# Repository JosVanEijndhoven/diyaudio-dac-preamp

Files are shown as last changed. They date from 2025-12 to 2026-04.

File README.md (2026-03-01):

# DACXO: Audio DAC and digital pre-amp with low jitter

overview photo

## Introduction

This [github repository](https://github.com/JosVanEijndhoven/diyaudio-dac-preamp) 
provides all HW and SW sources of my DIY audio DAC design.
The audio 'Digital-to-Analog Conversion' is the heart and main aim of the design.
However, more audio device functionality was built around that:

- Functionality for a digital pre-amp is provided, with input selection
  and volume control. Inputs are optical and coax s/pdif, HDMI-arc, and a network DLNA audio player.
- The control UI (user interface) is created with [esphome](https://esphome.io/).
  Besides the front panel control knob, this also provides remote control from a mobile phone
  and/or integration in [home assistant](https://www.home-assistant.io/) automation environments.
- The core DAC design aims for high-end audio, with a focus on low jitter, not
  aiming to reach low component cost.

The intention of this repository is to show some solutions across a wide range of design choices,
potentially of interest to other DIY audio enthousiasts.
Supporting purely cloning the full hw/sw design is not the intention,
as some design files might be outdated for the various tools and components that were used:
the design start was around 2015. (But its development still continous in 2026...)
This DAC design builds on previous experience: it is already my 5th design.

Only in december 2025 I started to upload my design in github, and thereby make it public visible.
I still have to spend further effort in documenting the design and its choices.

The device name **DACXO** is related to:
- Its good **X**tal **O**scillator and low-jitter clocking.
- Its **X**tra **O**riginal clock synchronization scheme on the s/pdif inputs.
- The now **X** [years](https://en.wikipedia.org/wiki/Roman_numerals) **O**ld circuit design when creating this open-source repository.
- As bonus, the domain name [dacxo](http://www.dacxo.com) was available.

## Contents

This repository contains all hardware and software design aspects:

- The [front control and remote UI software](./esphome-ui/) based on a commercial *esp32-s3* board with display.
- The [digital signal processing board](./dacxo-hw/PCBs/PCB-dacxo/), schematics and PCB design.
- The [logic configuration of the FPGA](./dacxo-hw/FPGA-content/) on that board,
- The [analog output board](./dacxo-hw/PCBs/PCB-opampout/), schematics and PCB design,
- A [Linux kernel audio device driver](./dacxo-sw/RPi-audiodevice/),
  so that the board can also be driven from various applications on a Rapsberry Pi.
- Addition of a Raspberry Pi as [network media player](./dacxo-sw/), relying on above audio device driver.

## Focus on Jitter

The main focus on this design is having good behavior on jitter (that is, achieve very low jitter).
Already for decades now, jitter is known to badly affect the sound quality of digital audio reproduction.
Unfortunately, achieving low jitter makes a device more expensive, and measuring jitter behavior requires expensive specialised equipment.
As result, many digital audio consumer products still show bad jitter behavoir.

The audible effects of jitter in a digital audio player are:

- Weak, uncontrolled, bass
- Unfocussed and unstable stereo imaging
- Unpleasantly sharp (metal-sounding) highs

Because many (cheaper) audio consumer devices behave badly in this respect,
the old vinyl record playing has risen again in popularity.
Luckily, good digital audio players don't show these artifacts,
and can sound really natural and convincing!

Presumably in large part due to jitter effects, this DAC design sounds significantly better than for instance the
[Cambridge Audio EXN100 player](https://www.cambridgeaudio.com/row/en/products/ex/exn100) which I bought early 2025, 
which costs around 2000 US$. (Just in my opinion and some of my audio-loving friends.)

For further background information on jitter in digital audio, you can easily find many sources on internet.

As a final note, jitter artefacts do not only occur in audio DAC (digital-to-analog conversion),
but similarly in analog-to-digital conversion (ADC).
So, a poor-quality studio recording (or home recording)
will introduce jitter artefacts in the digital audio stream.
Once in there, these jitter artefacts cannot be removed anymore:
a bad recording will sound bad forever. 
A good low-jitter player cannot improve a bad recording.
Unfortunately, it seems to me that there are many bad-quality recordings around...

## License
All source and configuration files provided in this repository are provided without any warrenty,
and under copyright and license:

Copyright 2025 Jos van Eijndhoven

[GNU General Public License v3](https://www.gnu.org/licenses/gpl-3.0.nl.html)

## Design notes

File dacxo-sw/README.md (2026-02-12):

# Audio stream DLNA renderer to the DAC

## Introduction

To stream audio to the DAC over wifi, a 'DLNA' network
interface is created.
This is realised with a tiny
[Raspberry Pi zero 2W](https://www.raspberrypi.com/products/raspberry-pi-zero-2-w/).

For streaming audio,
(DLNA renderer)[https://github.com/hzeller/gmrender-resurrect] software is installed. This allows other application to send audio,
in particular [BubbleUpnp](https://play.google.com/store/apps/details?id=com.bubblesoft.android.bubbleupnp),
or maybe [VLC](https://github.com/videolan/vlc).

The received audio is passed to the DAC board through an *i2s* interface.
[i2s](https://en.wikipedia.org/wiki/I2S) in general allows a configuration choice whether the
sender or the receiver provides the clock signal.
Here the DAC provides its 'master' clock,
which means that there is no synchronization issue.
That is a major advantage over using s/pdiff interfaces.

## Installing the DLNA renderer

The (gmrender-resurrect)[https://github.com/hzeller/gmrender-resurrect]
software is installed on the *raspberry Pi zero 2w* according to
its description. That description is fine: although it mentions
*gstreamer1.0* in some of its package names, it actually
instals the recent versions of that.

Created *gmedia* user to run the daemon:
```
sudo adduser --system --ingroup render --no-create-home gmedia
sudo usermod -a -G audio gmedia
sudo usermod -a -G i2c gmedia
sudo usermod -a -G gpio gmedia
```

Edit the `scripts/init.d/gmediarender` file, modifying a few lines such as:
```
DAEMON_USER="gmedia:audio"
UPNP_DEVICE_NAME="MyDac"
ALSA_DEVICE="plughw:DACXO"
start-stop-daemon -x $BINARY_PATH ... --mime-filter audio
```
(On the long `start-stop-daemon` line, add the `--mime-filter audio` option
restricting this *dlna renderer* to only play audio, not video.)

Then, install it with:
```
sudo cp scripts/init.d/gmediarenderer /etc/init.d
sudo update-rc.d gmediarenderer defaults
```

## System load for playing audio streams over wifi

My small *Rapsberry Pi zero 2W* seems just fine and powerful enough
for this task. For example, a *high resolution* FLAC-encoded stream can easily be
sent to this *DLNA renderer*.
A *96K* samplerate and *24-bits* per sample stereo FLAC stream has
a variable bandwidth of roughly 400KBytes/sec. For such a stream,
the renderer uses about 7% cpu load (on 1 of the 4 available cores)
and takes about 25% (or 125MB) of the available 512MB memory.

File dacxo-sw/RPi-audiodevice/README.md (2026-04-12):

# Audio device driver for Linux

## Introduction

This DAC design initially/traditionally focussed on using the four s/pdif inputs on its digital board: two coax and two optical inputs.
However, the board also provides a fifth digital audio input:
an [i2s](https://en.wikipedia.org/wiki/I2S) input intended to connect
an audio network streaming device in the form of a Raspberry Pi.
I chose a tiny
[Raspberry Pi zero 2w](https://www.raspberrypi.com/products/raspberry-pi-zero-2-w/) for this purpose.

Connecting a Raspberry Pi through its *i2s* interface (in this design) keeps the DAC as
master clock, and uses the Pi as clock slave on this interface:
- This has the advantage of a clean clock with minimal jitter without any clock synchronization issues.
  (In contrast with using the classic s/pdif inputs.)
- It requires that -per song- the Pi informs the DAC board on the required sample-rate.

So, where the *i2s* interface is used to pass the audio data,
the Pi also uses an [i2c](https://en.wikipedia.org/wiki/I2C) connection
to the DAC board to communicate on the sample-rate.
In practice, this also enables the Pi to control the audio volume, input selection, and power-state,
and make the Pi a full-featured audio streamer.

For the Pi to obtain such control, it needs an audio device driver.
Such Linux kernel audio device driver is provided in this directory.

## Contents
- Creating the development setup
- Building and installing the device driver
- Initial testing of the device driver
- Activating the device driver on boot
- Choosing the DAC as system default audio device

## Creating the development setup
To build the device driver kernel modules, I opted (and would recommend)
for the simplicity of doing that on the target Raspberry Pi itself.
This as opposed to a more elaborate setup of a Pi cross-development environment
on another desktop computer.
Building and installing the kernel modules is highly dependent on the
precise version of the Linux kernel. Local development avoids a potential mismatch.
Also, after an OS update which increments the kernel version, these modules
can be easily rebuilt. 

The start environment is the plain [64-bit Rasberry Pi OS](https://www.raspberrypi.com/software/operating-systems/).
The *Lite* version, without desktop environment, is fine: we will only use
the Linux command-line [through an 'ssh' connection](https://www.raspberrypi.com/documentation/computers/remote-access.html#ssh).
Optionally, it might also be convenient to [share your Pi home directory](https://www.raspberrypi.com/documentation/computers/remote-access.html#samba) with your desktop.

All further text in thie README assumes that you are logged-in on the Pi,
maybe through *ssh*, and execute the commands locally on the Pi.

The Raspberry Pi OS comes with `gcc` and the required `include` files pre-installed, so we don't need to install that.

To obtain a copy of the source code in the Pi, it is easiest to install
`git`:
```
sudo apt install git
```
Since this git repository contains many more things, for just building
the Pi device drivers you probably want to `checkout` only the relevant directory.
That gains speed and reduces the size on your Pi's memory card.
```
git clone --filter=blob:none --sparse  --depth 1 git@github.com:JosVanEijndhoven/diyaudio-dac-preamp.git
cd diyaudio-dac-preamp
git sparse-checkout set dacxo-sw/RPi-audiodevice
git checkout
```
Now, `cd dacxo-sw/RPi-audiodevice` to see what you got and start building.

## The device driver source code files

The device driver C-code sources consists of various files in the `bcm` and `codecs`
sub-directory.

1. `bcm/dacxo_bcm.c`: This is 'board control module', it specifies that there is an *i2c* connection to the board, to control the FPGA and the two pcm1792 dac chips.
Around [dacxo_bcm.c:343](dacxo_soc_modules/bcm/dacxo_bcm.c#L343)
the *i2s* interface mode is set to `DACXO_DAIFMT`.
This is defined in `codecs/dacxo.h` with (among others)
the value of `SND_SOC_DAIFMT_CBP_CFP`. This configures the Pi *i2s* interface
as clock slave, for both the bit-clock and the word-clock.
This board driver also takes care of powering-up the board if it would be in *standby*.

2. `codecs/dacxo_codec.c`: It implements the *per audio stream*
dac sample rate control with the i2c registers in the FPGA.
3. `codecs/dacxo.h`: constants regarding the codec, also passed to the `dacxo_bcm.c`.
4. `codecs/pcm1792a.h`: constants to drive the pcm1792a on-chip registers. code.

## Building and installing the device driver

The `Makefile` in this `RPi-audiodevice` directory defines targets for many actions.

The `dacxo` device driver consists of two kernel modules:
- `dacxo_bcm`, the *board control module*, or *card driver*.
- `dacxo_codec`: the *codec* module.

To just build these in the current directory tree, you do:
```
make modules
```
The two built modules can be seen with `ls -l */*.ko`.

Besides these kernel modules, the driver needs a *device tree overlay*.
This specifies how/where these modules need to hooked into the Linux device tree.
This *device tree overlay* also needs to be compiled. So run:
```
make overlays/dacxo.dtbo
```

If there are no fatal errors, proceed with installing these build results
in the Pi system directories. The following command uses `sudo` and might
ask for your password:
```
make install
```
It would be good to have the `i2c` and `i2s` connections activated in
the `/boot/firmware/config.txt`, by adding (uncommenting) the
following two lines. If they were absent, do a reboot:
```
dtparam=i2c_arm=on
dtparam=i2s=on
```

Now one can load the `dacxo` driver at runtime in the kernel:
```
make test_dtoverlay
```
The above command will show some log output (from `dmesg`), from
loading and initializing the driver.

When encountering issues, the installation and overlay can be undone with:
```
make uninstall
```
Also, local build artefacts can be removed with:
```
make clean
```

Until now this is all reasonably safe: a next reboot will not yet
automatically load the driver, so there is no risk of destroying a clean boot.

The driver code and its overlay were developed on the 64-bit Pi OS of December 2025,
debian version 13 (trixie), with Linux kernel *6.12.62+rpt-rpi-v8*.
Recent history has shown that the Linux audio (ALSA) kernel api's do not remaain very stable over time.

## Initial testing of the device driver
If making the `test_dtoverlay` seemed OK, without errors, audio can be played!
For instance by:
```
make sound
```
The card properties that the driver exposes to ALSA can be seen with:
```
make show_card
```
The low-level device registers on the *i2c* bus (in the three different
i2c devices of this card) can be examined at runtime
through the Linux *debugfs* mechanism with:
```
make show_registers
```
Note that on receiving fisrt audio, this device driver will automatically
power-up the DAC if it was in standby, and select its *i2s* input.

## Activating the device driver on boot
After some testing, the installed driver can be made to
automatically active on every boot.
There are two mechanisms to achieve this. Choose one of:
1. Add a line in `/boot/firmware/config.txt`:
```
dtoverlay=dacxo,sync_pin=27
```
2. Use the Linux *systemctl* service mechanism for this:
```
make install_service
```
The latter option allows to *start* and *stop* this at runtime,
which had my preference.

## Choosing the DAC as system default audio device
Note that the above `make install` will also install the `etc/asound.conf`
as provided by this repo. That makes the new *dacxo* device as the default
audio device. On my *Pi zero 2w*, the default audio device is otherwise
its hdmi output. Of course, alternatively, one can probably also configure
the `dacxo` audio output specifically for the audio media player application.

This device driver announces to the Linux ALSA system that it accepts audio
streams with samplerates: `44100`, `48000`, `88200`, `96000`, `176400`, and `192000`.
It accepts audio formats with `16` or `24` bits per sample, and 2 channels (stereo).

In the proposed `asound.conf`, the default audio is created with `type plug`,
which means that the kernel can *plug* format conversions if deemed necessary
to play some audio stream. This is needed in particular for playing
24-bit FLAC streams: after basic decoding (such as by the `flac` application),
a *compact* 3-bytes-per-sample stream is created.
The Pi cannot send such stream to its *i2s* output with DMA.
The `type plug` will automatically insert a software filter that performs
*zero-padding* to extend each sample to 32-bit.
Such *plugging* would also be done for instance for mono audio streams.

## Raspberry Pi I/O pins used by this driver

The below diagram shows the pinout of the three *i2s* signals and two *i2c* signals on the Pi
40-pin GPIO connector:

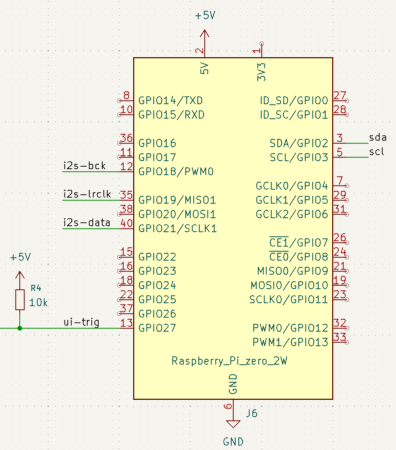
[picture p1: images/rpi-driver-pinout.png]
RPi schematic diagram of I/O


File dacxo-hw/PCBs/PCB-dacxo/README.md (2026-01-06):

# Audio DAC main digital PCB
## Introduction
The 'digital PCB' implements the most interesting parts of this DAC design.
It is provided here with a global description below, pdf files
of the [schematics](./dac5-schem-eurocircuits-20150214.pdf) and
[PCB layout](./dac5-eurocircuits.pdf), and the original [KiCad](https://www.kicad.org/) design files.

## Board inputs and outputs

The PCB provides five digital audio inputs:
  - Two optical s/pdif inputs
  - Two coax s/pdif inputs
  - One i2s input

The analog audio outputs are *intermediate*, needing further handling by a separate analog PCB.
These outputs are the direct chip outputs of the (now mounted) pair of *PCM1792A* DAC chips.
They operate in *dual mono* mode, and provide for each audio channel a differential current output of 2x 15.6mA p-p, on top of a DC current offset of 12.4 mA.

For control of the board, an i2c input is used.
An external microcontroller board shall be used to implement the control. This includes settings such as:

- Setup initialization of chip operating modes.
- Audio volume and balance
- Input source selection
- Power on versus standby mode

Besides these settings, the microcontroller can read status information such as:

- currently selected xtal oscillator
- signal presence and sample rate of the current s/pdif input
- current status of the audio buffer and clock rate adjustment (see PLL description below)

Based on the s/pdif received audio signal, the board hardware will automatically select
one the two xtal oscillators and a clock divider to match the samplerate of the signal.
This logic is implemented in the on-board FPGA, a *MachxXO2-100* from Lattice Semiconductor,
denoted *U306* in the [schematics](./dac5-schem-eurocircuits-20150214.pdf).

For power supply, the board takes a separated:

- Analog supply as a raw (unrectified) input from 2x7V transformer.
- Digital supply as a raw 5V dc from an external small smps (switch-mode power supply).
  The chosen 1A (5 watt) power is plenty for this design.
  I selected a high quality type, approved for medical applications, manufactured by Mean Well.

Furthermore, the board provides:

- a USB input for programming the FPGA.
- several connectors for easy access to measure and debug various on-board signals.
- a few LEDs for quick visual feedback on status.

## s/pdif receiver

The CS8416 (*U503* in the [schematics](./dac5-schem-eurocircuits-20150214.pdf))
is used to receive the s/pdif datastream and select between
four inputs: two optical and 2 coax. The coax inputs are implemented with high-frequncy isolation transformers
for a good isolation of common-mode disturbance. In general, coax connections seems to have a preferrable
signal transfer.

The PCB allows the CS8416 to operate in eiter its 'SW mode' or its 'HW mode'.
A 47k resistor can shall placed in either *R505* for SW mode, or in *R501* for HW mode.
Initially, during board testing, SW mode was used. In the final design, HW mode is used,
where the various control wires are provided by the FPGA.
(The two modes rely on a different FPGA content.)

The audio clock which is recovered by the CS8416 from s/pdif is in sync with the audio bitstream,
and used to clock the audio data into the FPGA buffer. This clock is considered *dirty* in this design,
so is NOT used for the output clock on the DAC chips.

## Achieving low jitter

To achieve low jitter performance, different causes of jitter need to recognized and addressed.
This is distinguished in aspects 1 to 5 below:

### 1. Oscillator (reference clock) stability
Low jitter in the main audio reference clock, corresponds to low oscillator phase noise.
This design uses the Crystek CCHD-957 crystal oscillator, which has the best phase noise specification I could find,
while easy to acquire in small volume. Phase noie is typically expressed in a frequency plot. A key number
would be the *-130dB noise level* at *100Hz deviation* from its center frequency.
The design actually uses two of these oscillators, at 45.1584 MHz and 49.152 MHz.
These frequencies correspond to 1024 * 44.1 kHz and 1024 * 48 kHz. Having both these clock frequencies
allows the playback of relevant audio sample rates without complex (non-power-of-two) resampling,
to avoid related conversion artefacts.

### 2. Re-clocking of digital audio signals
To achieve low jitter on the signals that enter the DAC chips, the audio data, audio bit-clock and audio word-clock signals
are *re-clocked*: they pass through a clocked register (U307 in the schematic) which is
clocked directly by the xtal reference clock. There should be absolutely minimal (best none at all) logic between
the crystal reference clock and the clock input of this register.
This shall minimise the build-up of jitter on signals that pass through logic gates.

### 3. Low-noise power supply on the digital ciruits
All CMOS logic gates have a gate-delay which strongly depends on the power-supply voltage.
You can easily check this on any *74hc* logic family datasheet. A gate delay of -lets say- 10ns can easily vary +/- 1 ns
when its powersupply voltage has small dips or peaks. That is an *enormous* variation in delay, as we aim for
jitter in the 10ps to 100ps range. Note furthermore, that we need to have a stable power supply voltage
*on the chip die itself*, not only on the external package pins.
This results in a preference for less logic per chip, less logic sharing a common power-supply pin.

In this schematic, the *3.3Vana* is made from a 2.5V reference, RC-filtered for noise,
and amplified/buffered with a low-noise opa2227 opamp.
This low-noise supply voltage is used for the crystal oscillators, the re-clock register,
and the digital supply of the DAC chips.
In *standby* mode, this *3.3Vana* with its off-PCB transformer is switched off.

The other digital circuitry (the FPGA and the s/pdif receiver) are supplied from a separate 3.3V 'digital' power voltage.
This same 'digital' power supply also provides a +5V to the front panel microcontroller
through the 4-pin i2c connector (P402 in the schematics).
The 'digital' power comes from an off-board +5V small SMPS (switch-mode power supply).
In *stand by* mode, this 'digital' power will remain on.

### 4. Reduce EMI-induced noise
Electromagnetic Interference (EMI) induced noise is caused by high-frequency
elecromagnetic fields that spread around the PCB surface, and can cause
signal degradation and jitter. (Here, with 'high frequency' we worry about
frequencies in the order of 100Mhz to 1GHz.)

For a clean supply voltage and reduced EMI fields, a well-designed
[power-supply decoupling](https://www.murata.com/en-eu/products/emc/emifil/library/knowhow/basic/s2-chapter06-p1)
is required on all digital ICs.
This is achieved by:

- a local power supply decoupling capacitor very close to each chip.
- a high-frequency-suppression chip-inductor in the power-supply line for each chip.

The inductor makes sure that the high-freqency switching currents remain local to the chip and its decoupling capacitor.
Keeping these currrents local (in a very small loop) strongly reduces the EMI noise around the PCB.

Furthermore, small (47R to 470R) series-resistances are inserted in series in many
of the audio data and clock lines. These reduce peak currents
and [high-frequency ringing](https://www.protoexpress.com/blog/how-to-reduce-ringing-in-pcb-designs/)
on these signals on the PCB.

### 5. Phase Locked Loop design
Creating a good-sounding DAC from s/pdif inputs (optical or coax) poses a major extra challenge on *clock synchronisation*.
Note that an i2s or usb sound input can easily and totally avoid this issue.
S/pdif audio is received with its own clock. Recovering that received clock from the s/pdif signal
inevitably leads to a bad (unstable, high jitter) clock signal.
Unfortunately, a local fixed-frequency crystal oscillator cannot directly replace
that 'bad' clock, because it typically deviates from the frequency of the received
audio data stream: crystal oscillators typically deviate by +/- 100ppm (or 0.01%) from the nominal frequency (and the received stream).
To overcome this potential difference in center-frequency, some solution must be implemented.

*Option 1:*
Directly using the s/pdif retrieved clock for the DAC output is only done in the cheapest designs,
with crappy sound quality. The local crystal oscillator is simply omitted.

*Option 2:*
Traditionally, in vintage designs,
a clean clock might be re-created with an analog 'phased locked loop' (PLL). Such PLL contains a VCO (or VCXO): an oscillator
of which its frequence can be slightly tuned by an applied input voltage.
If the PLL has a low-frequency and low-noise filter for the control voltage, the jitter in the re-created clock
can be much lower then in the s/pdif-recovered clock.
In theory this can be good, but in practice this is extremely hard. Even good-quality VCXOs (voltage controlled crystal
oscillators) exhibit *much* higher jitter then the best fixed-frequency crystal oscillators.

*Option 3:*
Currently used by most DAC designs: The DAC always already contains a digital filter for purposes of sample rate
conversion (translating all digital sources to a common rate for the output) and oversampling (creating a
higher sample rate on the output). Now, if a 'dirty' input clock that provides the audio samples slightly deviates
in its average from the local fixed-frequency crystal oscillator, lets say by 100ppm, then after every 10.000 samples
some *new* sample must be inserted, or some received sample must be dropped. The digital filter
can then be used to 'smear' this sample artefact over a longer period.
As result, short-term (fast) jitter in the dirty input clock nicely disappears,
but very slow jitter in the input and deviation in the average data rate,
result in distortions (modified values) in the filtered output.

*Option 4:*
This DAC design takes a new approach, as far as I know. The input samples with their 'dirty' s/pdif clock are
stored in a cyclic buffer (a queue of samples). This buffer can be relatively small,
in this design it currently is 682 samples.
The high-quality crystal clock is used to take samples out of this queue to send to the DAC chips.
Note that this design uses an xtal clock of 1024x the standard (44.1kHz or 48kHz) sample rate.
If the buffer runs low (nearly empty), the clock divider to create the sample rate (word-)clock, is adjusted to be 1025.
Similarly, if the queue runs nearly full, the clock divider can be adjusted to 1023.
Effectively, this creates a nearly 0.1% deviation in the output clock rate.
Switching the output clock frequency +/- 0.1% occurs at low rate:
Suppose 640 samples in the queue need to be flushed or filled
at the modified frequency, that would take (640 / (samplerate x 0.1%)) is about 14 seconds.
Having the DAC speed-up or slow-down the output rate by 0.1% after about 14 seconds is truly in-audible.
For a high-resolution 24bit 96kHz datastream the duration of the updated clock speed is still about 6.6 seconds.
This design choice can be considered a digital PLL, with a very low-frequency filter loop.
Obviously, the good properties are that a) a high-quality low-jitter clock can be used,
and b) all original audio sample values are retained as is.

Because the number of buffered samples remains relatively small, it imposes a delay of at most 14 millisecond,
which means that the audio will remain in sync with video if the audio stream comes from an attached TV.

## i2s input

The extra i2s input is on the PCB as *P408*.
In i2s mode, the PCB assumes clock master mode, where it provides the bit-clock and word-clock to the interface.
So the peripheral (audio streamer) should:

1. Configure its i2s output in clock slave mode.
2. Pass control information from the audio stream through i2c to the FPGA to indicate
   the required sample rate.

In this clock master mode, there is no need to synchronize with any other clock.
Therefor, the fifo audio buffer is not used, nor is the +/- 0.1% clock rate adjustment.

On *P408*, the following pin assignment is used (set by the FPGA configuration):

- pin 1: gnd
- pin 2: audio data input
- pin 3: word clock output
- pin 4: bit clock output

After buffering with the crystal clock, these signals are passed as-is to the PCM1792 DAC chips.
So their format (e.g. msb-first, left aligned) should match.

## Selection of DAC chip
The PCB provides footprints for two different DAC chips: a pair of PCM1792A, or alternatively a pair of WM8741.
This is intended for comparison, but for now only the PCM has been used.
Clearly, only one of those pairs should be mounted!

## FPGA programming
The FPGA is a [Lattice Semiconductor MachXO2 family](https://www.latticesemi.com/en/Products/FPGAandCPLD/MachXO2)
device, in particular the LCMXO2-1200HC-4TG100I.
This FPGA features internal configuration storage, so no extrernal flash memory is needed.
It is housed in 100-pin TQFP package, which can still (barely) be hand-soldered on the PCB:

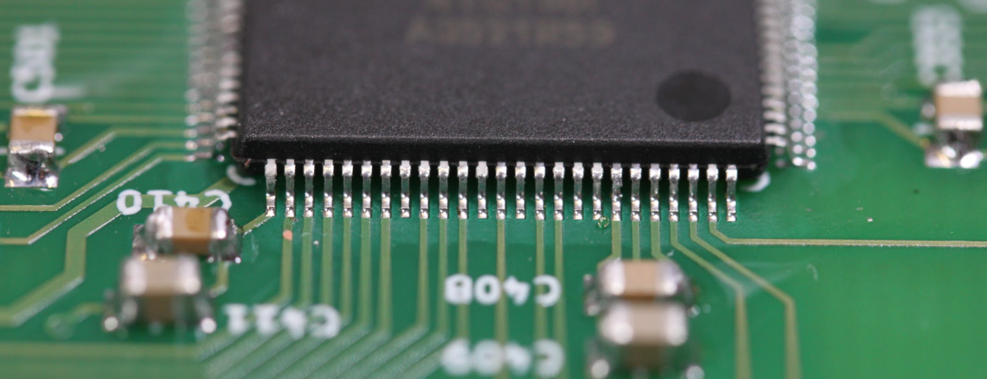
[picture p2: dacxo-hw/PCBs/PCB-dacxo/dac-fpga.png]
FPGA soldering


For easy programming of the onboard FPGA, a USB-to-jtag module is added to the PCB, denoted as *U401* in the schematics.
This is a DLP-USB1232H module from DLP Design. It is only used for programming the FPGA. During normal DAC
operation the module can harmlessly stay in place or can be removed.
During programming, the PCB takes +5V from this module, and no other external power is needed.
Note that there exist some late PCB wiring patches around its connection.

## On-board LEDs for diagnosis
The PCB has a number of LEDs that were convenient during early board
testing and debug. These are five bi-color (red-green) LEDs.
Their on/off status is according to the following table in matching top-down order:

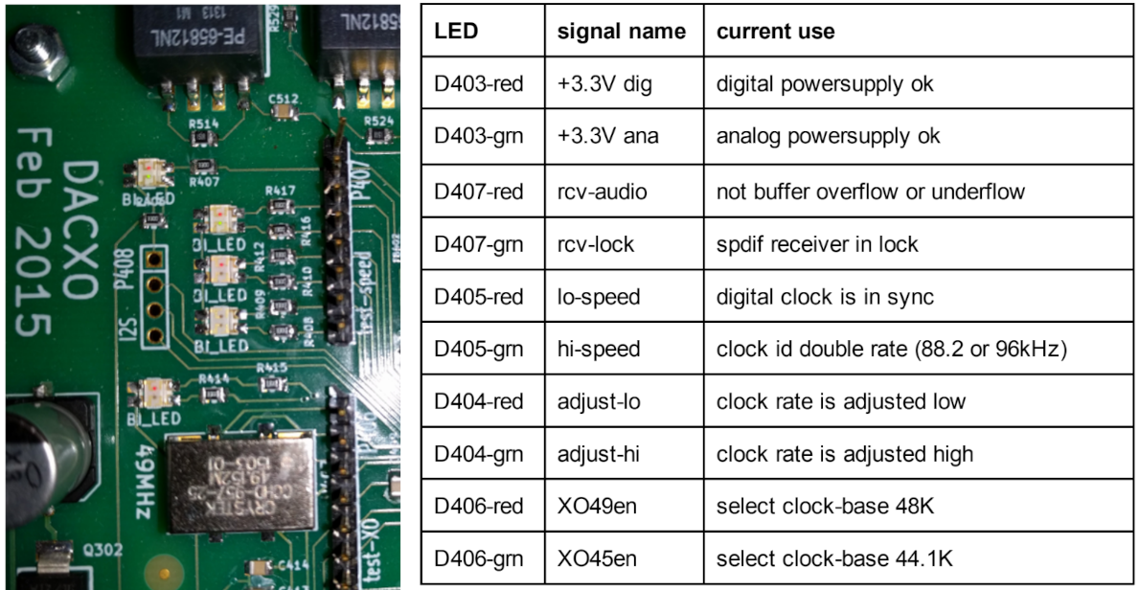
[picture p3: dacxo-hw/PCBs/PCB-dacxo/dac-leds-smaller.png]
LED status usage


## Late patches on the digital PCB
After assembly and test, a couple of small patches were done. These are not shown in the
original Kicad schematics: those still belong to the PCB design.

1. Add a small rectifier diode from '+5Vana' to 'V5raw' for protection against power-up errors.
2. 'U403' (for jtag programming) was badly connected: Lift 'pin1' to de-connect from the pcb,
  connect it to 'pin15' and 'pin8', and connect that triple to 'gnd'.
3. Replace R503 (47k) with 47 ohm.
4. Add a 4k7 resistor from 'rcv-rst' to 'gnd'.

Details on 2:
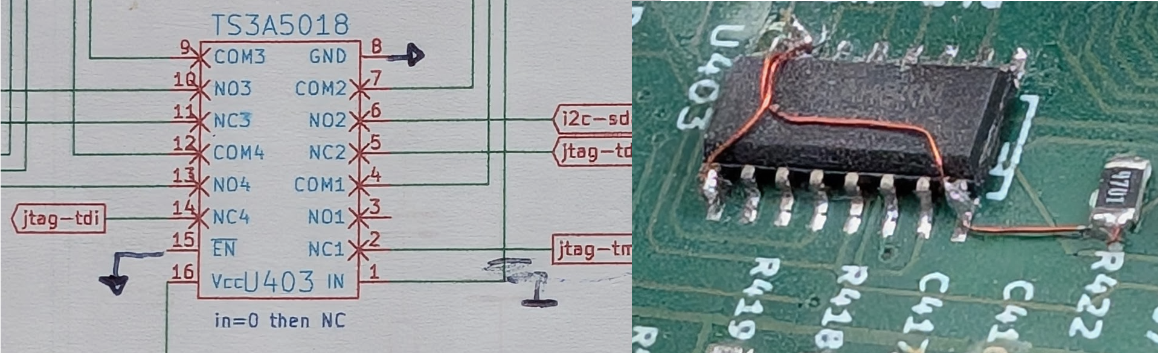
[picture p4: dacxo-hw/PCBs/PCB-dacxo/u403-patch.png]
patch on U403

Pin 1 got lifted from the PCB, which is hard to see in the photo.

Details on 4:
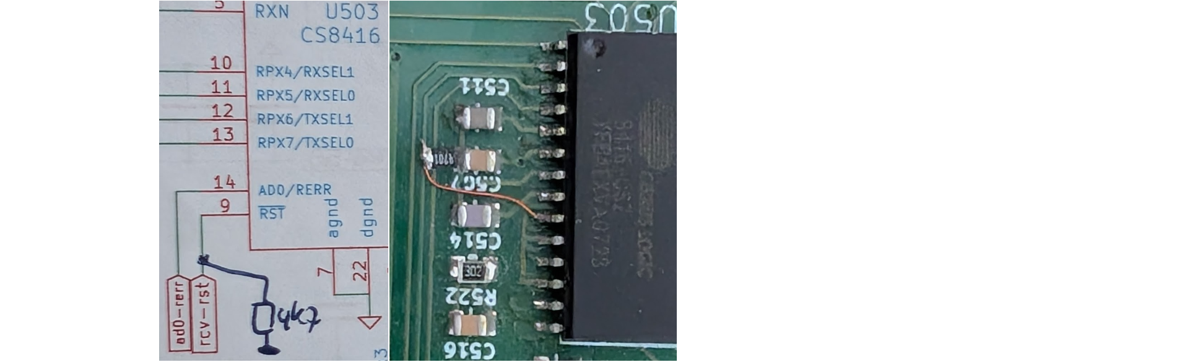
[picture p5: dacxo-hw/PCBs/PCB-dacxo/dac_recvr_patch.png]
patch on u503


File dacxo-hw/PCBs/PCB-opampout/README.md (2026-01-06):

# Analog output stage
## Introduction
This PCB provides a textbook style opamp-based analog output to accompany the digital PCB.
It was designed to function as basic reference (starting point) for other
more high-end analog audio alternatives.

The main functionality of this board is:

- Implement the current-to-voltage conversion that is needed for the (current output of) the PCM1792a DAC chips.
- Create stereo balanced output on a pair of XLR connectors,
  next to a conventional (single-ended) cinch connector.

The [schematics](./SchemaOutput-20131124.pdf) and the
[PCB layout](./outputstage-layout-20131111.pdf) can be viewed in pdf.
The original [KiCad](https://www.kicad.org/) design files are also provided here.

## Analog opamp output circuitry
Each of the four audio signal inputs should handle a DC input of 12.4mA with a max signal of +/- 7.8mA peak,
and keep that pin at virtual gnd voltage.
The output audio voltage is about 1.4Vrms on each of the four output pins,
which means 2.8Vrms on the differential XLR output.

The first stage of opamps (U202 and U204 in the schematic) are used for current-to-voltage conversion.
The second stage of opamps (U201 and U203) are used for differential amplification
of the positive and negative signal outputs of the DAC chips.
This differential amplification is used for both:

- Filtering out common-mode distortion and power-supply artefacts, resulting in clean audio output.
- Filtering out the DC offset that is part of the PCM1792A output current.

To achieve good common-mode and DC suppression, it is needed that both of these stages
are accurately balanced. For that purpose, this implementation uses 0.1% accurate resistors
to set the opamp gains. Furthermore, the PCB provides empty posistions to mount extra resistors in
parallel to the 'main' resistors: this allows optional fine-tuning of the balancing,
if the initially obtained balance would not be satisfactory.
For now, these extra resistor positions are not mounted.

Due to accurate balancing, the analog outputs can be DC coupled to a power amplifier,
which avoids potential signal disturbance from an output series capacitor.

The pcb has dil-8 footprints for all 6 (dual-) operational amplifiers.
This is to mount sockets for easy exchange of opamp types.
The schematics show LME49720 type dual opamps as default.
These are good low-noise, low distortion, and low offset opamps, intended for audio applications.
Later, I inserted a different type: four OPA1642 for the audio signal, and two NE5532 in the power-supply.
The OPA1642 supposedly gives better sound in this circuit with common-mode audio signals,
due to their unique voltage-independent input capacitance.

For resistor type, the design uses MELF 'MMA 0204' professional grade Vishay Beyschlag resistors.
These resistors have a decent *current noise* specification in their datasheet.
I would recommend to not buy any alternative resistor types for high-end audio
that are not provided with a specification of their (current-) noise.
In other designs I have preferred their larger 'MMB 0207' versions,
as these have a significantly better noise specification.
Unfortunately, at that time, I could not easily buy those larger versions with a 0.1% accuracy specification.

## High-frequency filtering

The output of the DAC chips contains significant high-frequency content which should better be filtered away
to not disturb the power amplifier:
- audio signal frequency components around multiples of the samplerate.
- high-frequency switching artefacts

To suppress those:

- The DAC current outputs have a small capacitor to ground on the digital PCB.
- each of the audio signal wires between the digital board and this analog board has a small series-inductor,
  and a resistor in parallel with that inductor. (This is not shown in the board schematics.)
  Together with the above capacitor that forms an RLC 2nd order
  filter, preventing most high-frequency components to enter the analog board.
- The first-stage 'current-to-voltage' opamps have a feedback capacitor to filter out the high-frequency spectrum.
- Just before the analog output connector, there is another RLC 2nd order filter.

The adopted opamp type has a significant high-frequency bandwidth. That is needed to
properly filter out these high frequencies without overdriving their differential inputs.

## Attenuation relay

The analog board has a '-20dB' attenuation relay for all its output audio signals.
This relay is controlled from the digital board:
its control signal is named *ext1* in the digital pcb schematics, and originates from a status register in the FPGA.

When the volume control of the DAC board is used, together with input selection,
this DAC takes the role of 'digital pre-amplifier'.
The output of the DAC would be directly wired to a power amplifier.
In such setup, the volume setting would most of the time be rather low, mostly not playing close to max volume.
When only the DAC chip digital volume would be used, that means that most of the time quite a number of
'high' (most significant) bits of the DAC conversion would not be used. That would effectively
reduce the number of bits (the resolution) of the DA conversion.

To alleviate this effect, the '-20dB' relay reduces volume on the analog output, allowing a higher volume on the DAC.
This relay is not under explicit user control: the microcontroller automatically uses this relay
for volume settings which are further then 20dB below max volume.

## Power supply

The power supply for the audio opamps is designed for very low noise and good ripple rejection.
The 'LM317' regulators are used as constant-current-source to feed a 7.5V zener diode.
Together that results in a very high PSRR (power supply rejection ratio).
The relatively large zener diode shows a lower dynamic resistance and lower noise voltage.
The zener noise voltage is low-frequency filtered by an RC-stage, and then amplified/buffered by the same
good quality audio opamp. Note that this opamp has a far higher PSRR then the LM317.
Four seperate regulated power supply voltages are made for positive and negative voltage,
and for the left and right audio channels.

To not exceed the opamp voltage operating conditions, the positive-voltage stabilization is done with
opamps that are powered from 0 to +24V.
Correspondingly, the negativevoltage stabilization is done with opamps that are powered from 0 to -24V.

The power supply input comes from a 2x15V transformer which is not mounted on the PCB.
This transfomer is switched on/off together with the digital PCB 'analog' power transformer,
through relay 'K301' in this schematics. As with the attenuation relay, this power relay is also
controlled from the digital PCB, signal named *ext2* in the digital pcb schematics,
originating from a status register in the FPGA.
This status register is controlled by the microcontroller software through the i2c bus.

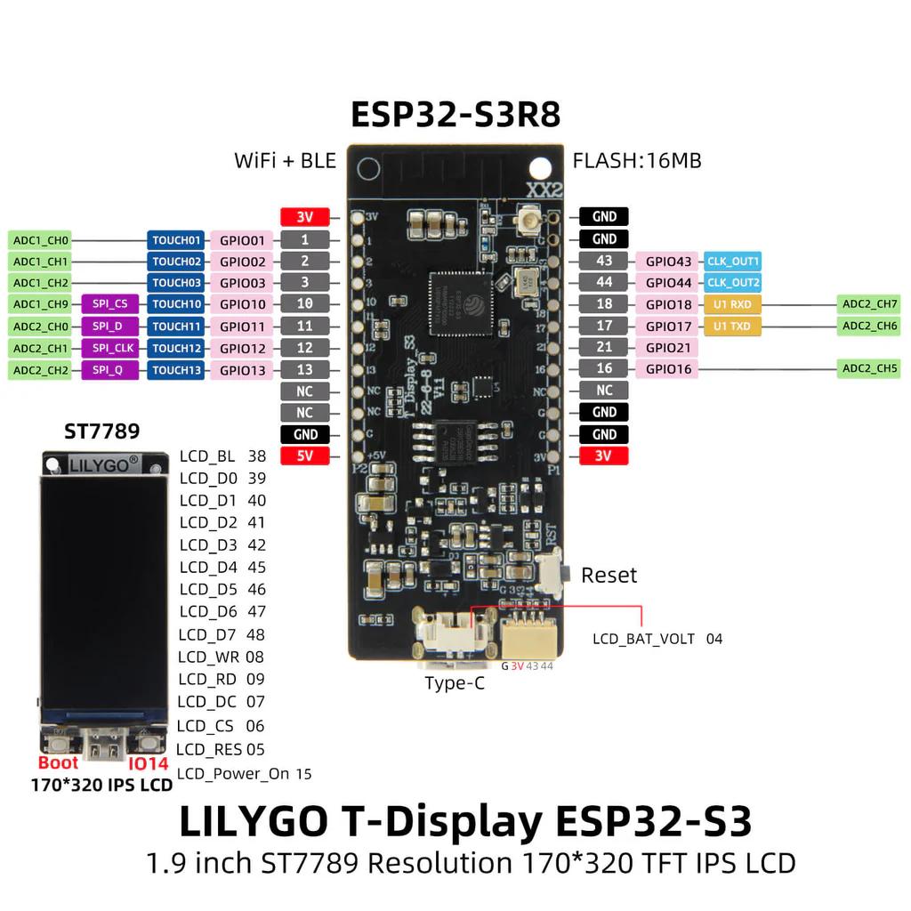
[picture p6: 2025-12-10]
esphome-ui/Lilygo-T-display_13_1024x1024.jpg

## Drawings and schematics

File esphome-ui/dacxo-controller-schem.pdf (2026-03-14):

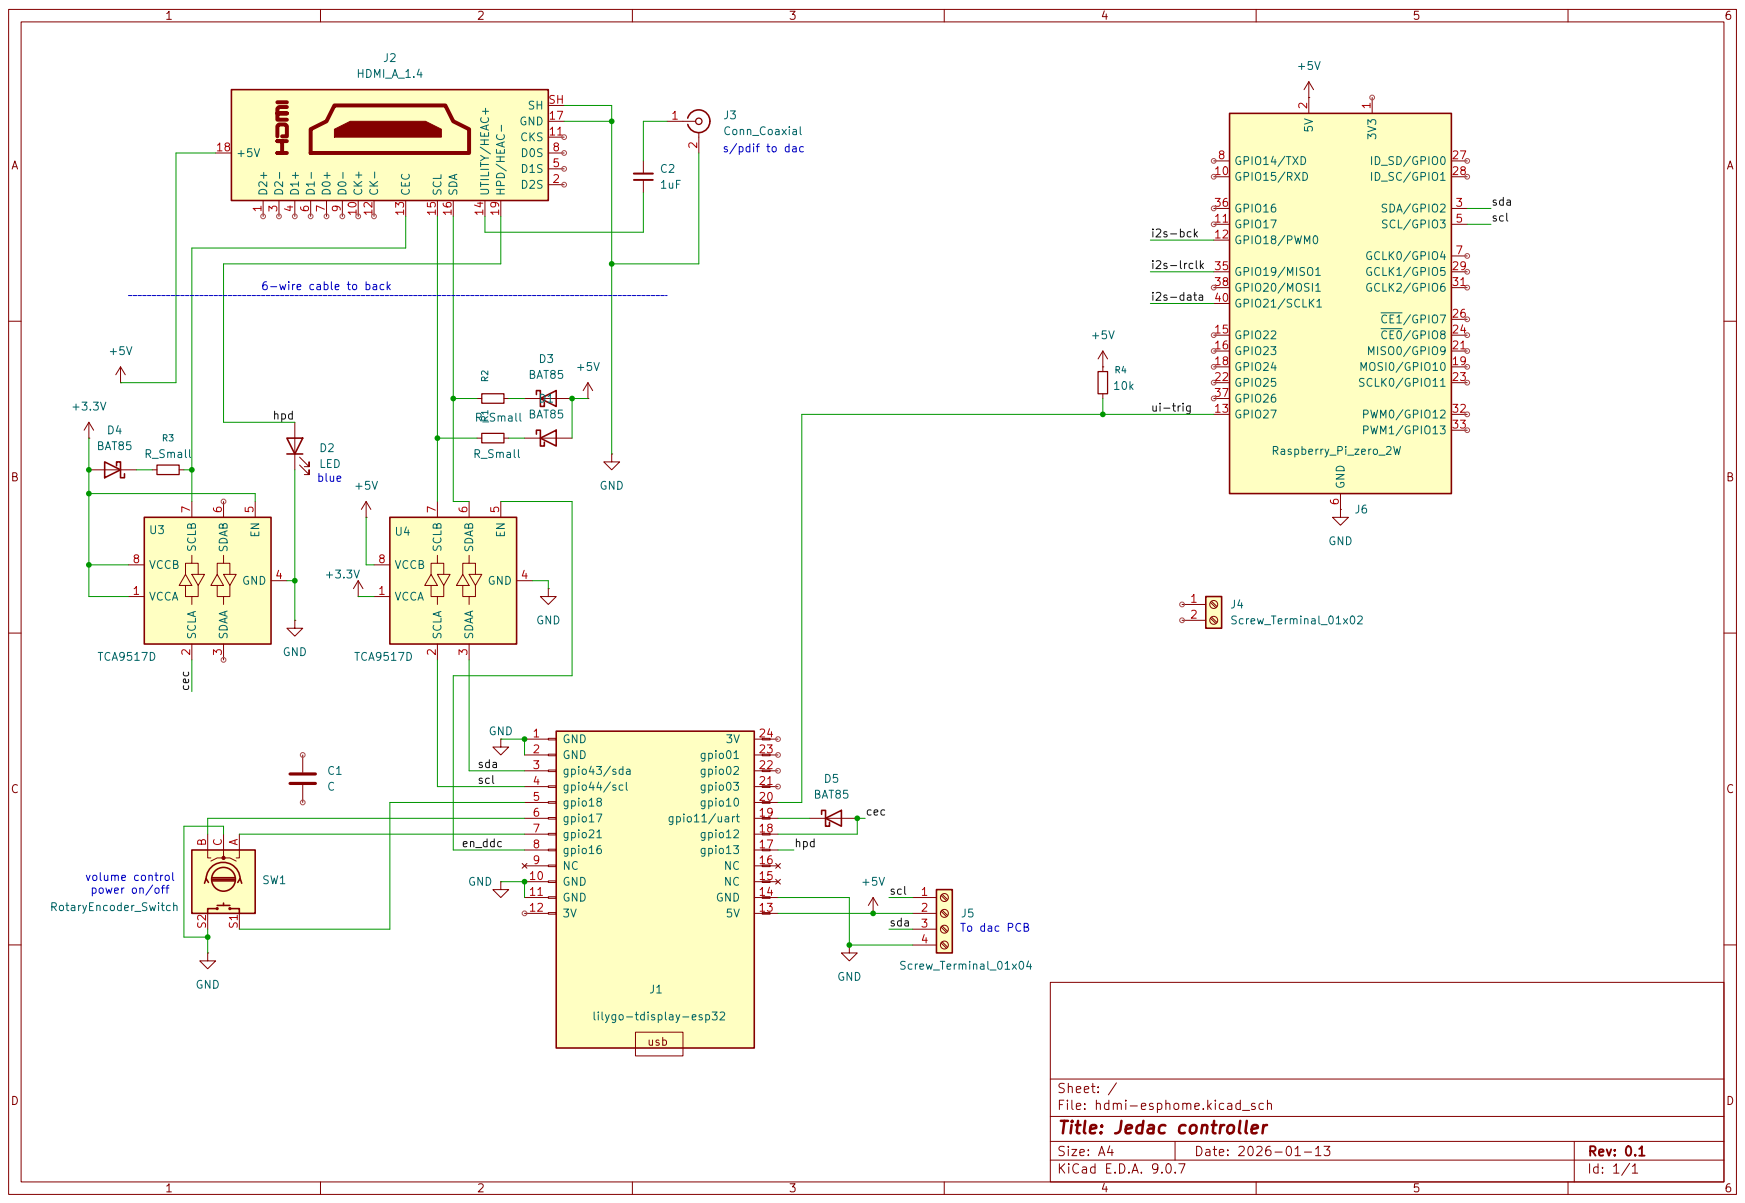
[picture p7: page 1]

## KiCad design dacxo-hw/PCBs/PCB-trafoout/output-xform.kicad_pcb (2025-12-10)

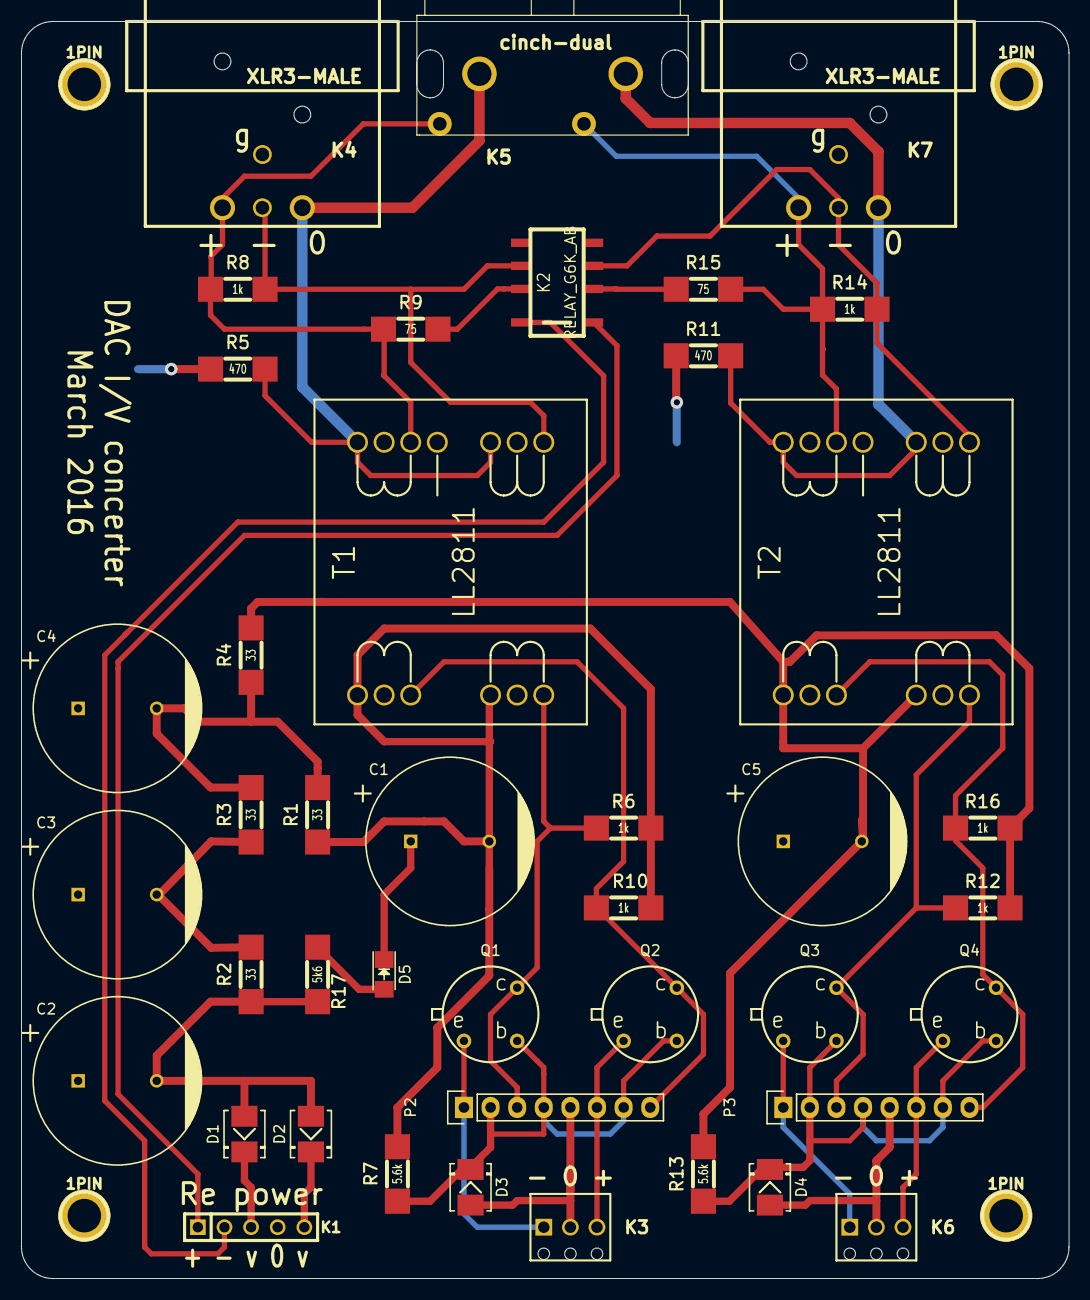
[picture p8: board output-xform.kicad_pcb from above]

Board: 2 copper layers, 100.0 x 120.0 mm, 46 parts (0 on the bottom side), 29 nets.

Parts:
1PIN, 1PIN#2, 1PIN#3, 1PIN#4: P***; screw-3.2
C1, C2, C3, C4, C5: 4.7mF; C_Radial_D16_L30_P7.5
D1, D2, D3, D4: DIODE; DO-214
D5: LED; LED_1206
K1: CONN_01X05; SIL-5
K2: RELAY_G6K_AB; G6K-2F-Y
K3, K6: CONN_3; SIL-3-screw
K4, K7: XLR3-MALE; NC3MAH
K5: cinch-dual; dualphono-kobiconn
P2, P3: CONN_01X08; Pin_Header_Straight_1x08
Q1, Q2, Q3, Q4: 2N2905A; 2N2905-TO5
R1, R2, R3, R4: 33; MMB0207
R5, R11: 470; MMB0207
R6, R8, R10, R12, R14, R16: 1k; MMB0207
R7, R13: 5.6k; MMB0207
R9, R15: 75; MMB0207
R17: 5k6; MMB0207
T1, T2: LL2811

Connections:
-12VL: C1.2, R1.2, R6.2, R7.2, R10.1, T1.3, T1.8
-12VR: C5.2, R4.2, R12.2, R13.2, R16.1, T2.3, T2.8
/-16V: C2.2, D1.1, D2.1, R2.1, R17.1
/ReN: K1.2, K2.8
/ReP: K1.1, K2.1
/baseL: D3.2, P2.2, P2.4, P2.7, Q1.2, Q2.2, R7.1
/baseR: D4.2, P3.2, P3.4, P3.7, Q3.2, Q4.2, R13.1
/inLneg: K3.1, P2.1, Q1.1
/inLpos: K3.3, P2.6, Q2.1
/inRneg: K6.1, P3.1, Q3.1
/inRpos: K6.3, P3.6, Q4.1
/primLneg: P2.3, Q1.3, R6.1, T1.1
/primLpos: P2.8, Q2.3, R10.2, T1.6
/primRPos: P3.8, Q4.3, R16.2, T2.6
/primRneg: P3.3, Q3.3, R12.1, T2.1
AGND: C1.1, C2.1, C3.1, C4.1, C5.1, D3.1, D4.1, D5.1, K1.4, K3.2, K6.2, P2.5, P3.5, R5.1, R11.1, T1.13, T2.13
unnamed: C3.2, R2.2, R3.1
unnamed: C4.2, R1.1, R3.2, R4.1
unnamed: D1.2, K1.3
unnamed: D2.2, K1.5
unnamed: D5.2, R17.2
unnamed: K2.2, R15.1
unnamed: K2.3, K7.3, R14.1, T2.9
unnamed: K2.6, K4.3, R8.1, T1.9
unnamed: K2.7, R9.1
unnamed: K4.1, K5.3, R5.2, T1.11, T1.16
unnamed: K4.2, K5.2, R8.2, R9.2, T1.14
unnamed: K5.1, K7.2, R14.2, R15.2, T2.14
unnamed: K5.4, K7.1, R11.2, T2.11, T2.16

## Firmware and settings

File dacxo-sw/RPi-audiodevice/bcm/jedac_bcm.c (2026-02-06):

/*
 * ASOC driver for the 5th generation DAC by Jos van Eijndhoven
 *
 * The DAC is based on a CS8416 receiver,
 * a MACH XO2-100 fpga and a CCHD-957 low-jitter clock,
 * a pair of PCM1792a dac chips in dual-mono configuration.
 * http://www.vaneijndhoven.net/jos/
 *
 * Copyright 2016 Jos van Eijndhoven
 * jos@vaneijndhoven.net
 *
 * This implementation was inspired from the 'bcm/raspidac3.c',
 * 'codecs/pcm512x-i2c.c' and the 'raspidac3-overlay.dts'.
 *
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
 * This program is distributed in the hope that it will be useful, but
 * WITHOUT ANY WARRANTY; without even the implied warranty of
 * MERCHANTABILITY or FITNESS FOR A PARTICULAR PURPOSE.  See the GNU
 * General Public License for more details.
 */

// Linux docs: https://www.kernel.org/doc/Documentation/sound/alsa/soc/machine.txt
 
#include <linux/errno.h>
#include <linux/module.h>
#include <linux/platform_device.h>
#include <linux/sched.h>
#include <linux/printk.h>
#include <linux/i2c.h>
#include <linux/gpio/consumer.h>
#include <linux/regmap.h>

#include <sound/core.h>
#include <sound/pcm.h>
#include <sound/pcm_params.h>
#include <sound/soc.h>
#include <sound/soc-dapm.h>
#include <sound/tlv.h>

#include "../codecs/jedac.h"
#include "../codecs/pcm1792a.h"

static const struct reg_default pcm1792a_reg_defaults[] = {
	{ PCM1792A_DAC_VOL_LEFT,   PCM1792A_DAC_VOL_LEFT_DEFAULT},
  { PCM1792A_DAC_VOL_RIGHT,  PCM1792A_DAC_VOL_RIGHT_DEFAULT },
  { PCM1792A_FMT_CONTROL,    PCM1792A_FMT_CONTROL_DEFAULT },
  { PCM1792A_MODE_CONTROL,   PCM1792A_MODE_CONTROL_DEFAULT },
  { PCM1792A_STEREO_CONTROL, PCM1792A_STEREO_CONTROL_DEFAULT },
};

static bool pcm1792a_reg_writeable(struct device *dev, unsigned int reg) {
	return (reg == PCM1792A_DAC_VOL_LEFT) || (reg == PCM1792A_DAC_VOL_RIGHT) ||
         (reg == PCM1792A_FMT_CONTROL)  || (reg == PCM1792A_MODE_CONTROL) ||
				 (reg == PCM1792A_STEREO_CONTROL);
}

static bool pcm1792a_reg_readable(struct device *dev, unsigned int reg) {
	return pcm1792a_reg_writeable(dev, reg);
}

static bool pcm1792a_reg_volatile(struct device *dev, unsigned int reg) {
	return false;
}

static const struct regmap_config pcm1792_regmap_config = {
  .reg_bits         = 8,
  .val_bits          = 8,
  .max_register     = PCM1792A_REG_MAX,
	.readable_reg     = pcm1792a_reg_readable,
	.writeable_reg    = pcm1792a_reg_writeable,
	.volatile_reg     = pcm1792a_reg_volatile,
	.reg_defaults     = pcm1792a_reg_defaults,
	.num_reg_defaults = ARRAY_SIZE(pcm1792a_reg_defaults),
  .cache_type       = REGCACHE_RBTREE, // This remembers values while DAC is not powered
};

static void jedac_set_attenuation( struct jedac_bcm_priv *priv, unsigned short vol_l, unsigned short vol_r);

/* sound card init */
static int jedac_pcm1792_init(struct i2c_client *dac, bool is_powered, bool is_right_chan)
{
	struct pcm_reg_init {
		uint8_t reg_nr;
		uint8_t value;
	};
	const struct pcm_reg_init inits[] = {
    { PCM1792A_FMT_CONTROL,  0xb0}, // reg 18: audio format left justified, enable att, no mute, no demp
		{ PCM1792A_MODE_CONTROL, 0x62},  // reg 19: slow unmute, filter slow rolloff
		{ PCM1792A_STEREO_CONTROL, (is_right_chan ? 0x0c : 0x08)} // reg 20: set mono mode, choose channel
	};
  pr_info("jedac_bcm: initialize pcm1792a(%s %s) i2c registers, power=%d\n",
		dac->name, (is_right_chan ? "Right" : "Left"), is_powered);

	struct regmap *regs = dev_get_regmap(&dac->dev, NULL);
	if (!regs) {
    dev_err(&dac->dev, "jedac_bcm: initialize pcm1792a(%s) i2c registers failed: no regmap?\n", (is_right_chan ? "Right" : "Left"));
		return -ENODEV;
	}

	if (!is_powered) {
	  regcache_cache_only(regs, true);
	}

	int err = 0;
	for (int i = 0; i < ARRAY_SIZE(inits) && !err; i++) {
		err = regmap_write(regs, inits[i].reg_nr, inits[i].value);
		pr_info("jedac_bcm: init pcm1792a:  write reg=%d, val=0x%02x, err=%d\n", inits[i].reg_nr, inits[i].value, err);
	}

	if (!is_powered) {
    regcache_cache_only(regs, false);
  }

	return err;
}

static int jedac_bcm_init(struct snd_soc_pcm_runtime *rtd)
{
	struct snd_soc_card *card = rtd->card;
  struct jedac_bcm_priv *priv = snd_soc_card_get_drvdata(card);

	pr_info("jedac_bcm: init(card=\"%s\", priv=%s)\n", card->name, ((priv == NULL) ? "NULL!" : "OK"));
	if (!priv)
	  return -EINVAL;

  // Note that the FPGA has already done its own init during its 'probe()'
  bool is_powered = false;
	unsigned int gpi1_val = 0;
  int err = regmap_read(priv->fpga_regs, REGDAC_GPI1, &gpi1_val);
	if (!err) {
		is_powered = (gpi1_val & GPI1_ANAPWR) != 0;
	}

	if (is_powered) {
		gpiod_set_value(priv->uisync_gpio, 0);  // pull-down 'uisync' pin: signal UI controller on change and stay silent
	}

	// the pcm1792 dac chip registers get initial assignment.
	// When they are not yet powered-up, this initialization remains in the regmap cache,
  jedac_pcm1792_init(priv->dac_l, is_powered, false);
	jedac_pcm1792_init(priv->dac_r, is_powered, true);

	if (is_powered) {
		gpiod_set_value(priv->uisync_gpio, 1);
	}

	return 0;
}

// replace the volume control from soc-ops.c
// which is inserted through e.g. #define SOC_DOUBLE_R in soc.h
static int bcm_vol_info(struct snd_kcontrol *kcontrol, struct snd_ctl_elem_info *uinfo)
{
	uinfo->type = SNDRV_CTL_ELEM_TYPE_INTEGER;
  uinfo->count = 2;       // Stereo
  uinfo->value.integer.min = 0;
  uinfo->value.integer.max = DAC_max_attenuation_dB;

	return 0;
}

static int bcm_vol_get(struct snd_kcontrol *kcontrol, struct snd_ctl_elem_value *ucontrol)
{
	pr_info("jedac_bcm:my_snd_soc_get_volsw() private_value = %04lx\n",
		kcontrol->private_value);

	unsigned short vol_l = kcontrol->private_value & 0x00ff; // lower 16 bits for left channel, 1dB units
	unsigned short vol_r = (kcontrol->private_value >> 16) & 0x00ff; // lower 16 bits for left channel
	ucontrol->value.integer.value[0] = -vol_l; // alsa operates with 0.01dB units
	ucontrol->value.integer.value[1] = -vol_r;
	
	return 0;
}

static int bcm_vol_put(struct snd_kcontrol *kcontrol, struct snd_ctl_elem_value *ucontrol)
{
	struct snd_soc_card *card = snd_kcontrol_chip(kcontrol);
  struct jedac_bcm_priv *priv = snd_soc_card_get_drvdata(card);
  uint16_t vol_l = ucontrol->value.integer.value[0];
  uint16_t vol_r = ucontrol->value.integer.value[1];
	
	// ALSA values are configured to 0 (mute) to 80 (0dB, max volume)
	pr_info("jedac_bcm: vol_put() ALSA vol_l=%u, vol_r=%d\n", vol_l, vol_r);

	uint32_t new_vol = (vol_l << 16) | vol_r;
	int changed = new_vol != priv->prev_volume;

	if (!changed || !priv->dac_l || !priv->dac_r)
	  return 1;
	
	priv->prev_volume = new_vol;
	jedac_set_attenuation( priv, DAC_max_attenuation_dB - vol_l, DAC_max_attenuation_dB - vol_r);

	return 1;
}

// define my volume scale as -80dB to 0 dB in steps of 1 dB, where the lowest volume does mute
/* 
 * min_db: -8000 (centibels)
 * step: 100 (1 dB in centibels)
 * mute: 1 (the minimum value 0 will be displayed as "Mute" in UI)
 */
static DECLARE_TLV_DB_SCALE(dac_db_scale, (-100 * DAC_max_attenuation_dB),
	                        (100 * DAC_step_attenuation_dB), 1);
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

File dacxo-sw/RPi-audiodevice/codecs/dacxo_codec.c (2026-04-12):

/*
 * Driver for the 5th generation DAC by Jos van Eijndhoven
 *
 * The DAC is based on a CS8416 receiver,
 * a MACH XO2-100 fpga and a CCHD-957 low-jitter clock,
 * a pair of PCM1792a dac chips in dual-mono configuration.
 * http://www.vaneijndhoven.net/jos/
 *
 * Copyright 2016 Jos van Eijndhoven
 * jos@vaneijndhoven.net
 *
 * The writing of this source-code was inspired by 
 * - //www.kernel.org/doc/Documentation/sound/alsa/soc/codec.txt
 * - https://github.com/raspberrypi/linux/blob/ ... sound/soc/codecs/pcm1792a.c
 *
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
 * This program is distributed in the hope that it will be useful,
 * but WITHOUT ANY WARRANTY; without even the implied warranty of
 * MERCHANTABILITY or FITNESS FOR A PARTICULAR PURPOSE.  See the
 * GNU General Public License for more details.
 */

#include <linux/module.h>
#include <linux/slab.h>
#include <linux/kernel.h>
#include <linux/device.h>
#include <linux/printk.h>
#include <linux/i2c.h>
#include <linux/gpio/consumer.h>
#include <linux/regmap.h>

#include <sound/core.h>
#include <sound/pcm.h>
#include <sound/pcm_params.h>
#include <sound/soc.h>
#include <sound/tlv.h>


#include "dacxo.h"

/* refrain from providing these defaults: that avoids potential mismatch with actual reg content
static const struct reg_default dacxo_reg_defaults[] = {
	{ REGDAC_GPO0,          0x00 },
	{ REGDAC_GPO1,          0x00 },
	{ REGDAC_GPI0,          0x00 },
	{ REGDAC_GPI1,          0x00 },
};
*/

static bool dacxo_writeable(struct device *dev, unsigned int reg) {
	return (reg == REGDAC_GPO0) || (reg == REGDAC_GPO1);
}

static bool dacxo_readable(struct device *dev, unsigned int reg) {
	return (reg == REGDAC_GPI0) || (reg == REGDAC_GPI1) || dacxo_writeable(dev, reg);
}

static bool dacxo_volatile(struct device *dev, unsigned int reg) {
	// return (reg == REGDAC_GPI0) || (reg == REGDAC_GPI1);  // run-time status
	return dacxo_readable(dev, reg);  // assume that other microcontroller can modify this state
}

const struct regmap_config dacxo_regmap_config = {
	.reg_bits = 8,
	.val_bits = 8,
	.max_register = REGDAC_GPI1,
	.readable_reg = dacxo_readable,
	.writeable_reg = dacxo_writeable,
	.volatile_reg = dacxo_volatile,
	// .reg_defaults = dacxo_reg_defaults,
	.num_reg_defaults = 0,  // ARRAY_SIZE(dacxo_reg_defaults),
	.cache_type = REGCACHE_RBTREE,
};

static int codec_set_dai_fmt(struct snd_soc_dai *codec_dai,
                             unsigned int format)
{
	pr_warn("dacxo_codec set_dai_fmt(format=%u) DUMMY\n", format);
	return 0;
}

static int dacxo_set_i2s_rate(struct snd_soc_component *codec, int samplerate, struct gpio_desc *sync_pin)
{
	int freq_base, freq_mult;
	
	if (samplerate == 48000 || samplerate == 96000 || samplerate == 192000)
		freq_base = 1; // enable other xtal oscillator
	else
		freq_base = 0; // default xtal oscillator
	
	switch (samplerate) {
		case 44100:
		case 48000: freq_mult = 1;
		break;
		case 88200:
		case 96000: freq_mult = 2;
		break;
		case 176400:
		case 192000: freq_mult = 3;
		break;
		default:
			freq_mult = 0; // illegal/unsupported samplerate
	}
	
	struct regmap *map = dev_get_regmap(codec->dev, NULL);
	if (!map) {
		pr_err("dacxo codec: regmap not found error!");
    return -EINVAL;
	}

	unsigned int gpo0_new = GPO0_CLKMASTER | (freq_base << 1) | (freq_mult << 2);
	unsigned int gpo0_curr = 0;
  int reg_err = regmap_read(map, REGDAC_GPO0, &gpo0_curr);
	if (reg_err || ((gpo0_new & GPO0_CLKMASK) == (gpo0_curr & GPO0_CLKMASK))) {
		return reg_err;  // return early when gpo0 needs no update
	}

	// Create the 'uisync' gpio signal, surrounding the write on the i2c bus
	gpiod_set_value(sync_pin, 0);  // pull-down 'uisync' pin: signal UI controller on change and stay silent

	// set clock config. Be carefull to not write the 'power' status bit:
	reg_err = regmap_update_bits(map, REGDAC_GPO0, GPO0_CLKMASK, gpo0_new);
	gpiod_set_value(sync_pin, 1);  // release pin

	if (reg_err == 0)
	  pr_info("dacxo_codec: set_i2s_rate: write GPO0=0x%02x with mask 0x%02x OK!\n", (int)(gpo0_new), GPO0_CLKMASK);
	else
	  pr_warn("dacxo_codec: set_i2s_rate: write GPO0=0x%02x, i2c write error=%d\n", (int)(gpo0_new), reg_err);
	return reg_err;
}

static int codec_hw_params(struct snd_pcm_substream *substream,
			     struct snd_pcm_hw_params *params,
			     struct snd_soc_dai *dai)
{
  struct snd_soc_component *codec = dai->component;
  struct snd_soc_card *card = codec->card;
  struct dacxo_bcm_priv *card_priv = snd_soc_card_get_drvdata(card);
	struct snd_soc_pcm_runtime *rtd = substream->private_data;
	struct snd_soc_dai *cpu_dai = snd_soc_rtd_to_cpu(rtd, 0);
	int samplerate = params_rate(params);
	int samplewidth = snd_pcm_format_width(params_format(params));
	int clk_ratio = 64; // fixed bclk ratio is easiest for my HW

	int err_clk = snd_soc_dai_set_bclk_ratio(cpu_dai, clk_ratio);
	int err_rate = dacxo_set_i2s_rate(codec, samplerate, card_priv->uisync_gpio);
	
	//	snd_pcm_format_physical_width(params_format(params));
	pr_info("dacxo_codec: hw_params(rate=%d, width=%d) err_clk=%d err_rate=%d\n",
		samplerate, samplewidth, err_clk, err_rate);

	return err_clk;
}

static const struct snd_soc_dai_ops codec_dai_ops = {
	.set_fmt	   = codec_set_dai_fmt,
	.hw_params	 = codec_hw_params,
	// .mute_stream = codec_digital_mute
};

static struct snd_soc_dai_driver dacxo_dai = {
	.name = "dacxo_codec",
	.playback = {
		.stream_name = "Playback",
		.channels_min = 2,
		.channels_max = 2,
		.rates = DACXO_RATES,
		.formats = DACXO_FORMATS
	},
	.ops = &codec_dai_ops
};

static int dacxo_codec_probe(struct snd_soc_component *codec)
{
  // Called *after* the below i2c_probe()

	// Retrieve the regmap that devm_regmap_init_i2c attached to the device,
  struct regmap *regmap = dev_get_regmap(codec->dev, NULL);
  // .. and explicitly tell the component to use this regmap
  snd_soc_component_init_regmap(codec, regmap);

	pr_info("dacxo_codec probe(): initialize component \"%s\", regmap %s\n",
	  (codec && codec->name) ? codec->name : "NULL",
	  (regmap) ? "OK" : "ERR");

	return 0;
}

static void dacxo_codec_remove(struct snd_soc_component *component)
{
	pr_info("dacxo_codec remove() codec\n");
}


static struct snd_soc_component_driver dacxo_codec_driver = {
	.name         = "dacxo codec driver",
	.probe 				= dacxo_codec_probe,
	.remove 			= dacxo_codec_remove,
};
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

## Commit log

2025-12-10 Gathered hw and sw files
    [audio-left.sch, audio-right.sch, calc.xlsx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]
2026-01-03 Many fixes in RPi device drivers: now compilable, unuse my old pcm1792a i2c driver
    [jedac5_bcm.c, jedac5_codec.c]
2026-01-03 small Makefile update, enable i2s in config
    [config.txt]
2026-01-06 Update description of dig pcb, add patch pictures
2026-01-06 Update description of opamp pcb
2026-01-06 Update description of dig pcb
2026-01-06 Update description of dig pcb with led status
2026-01-06 Update description of dig pcb: add dac solder pic
2026-01-09 Update jedac drivers and dts to add gpio pin
2026-01-20 Small driver updates, diagnostic prints
2026-01-20 Try to resolve missing call to probe on pcm179x
    [jedac5_bcm.c]
2026-01-20 reestablish my own pcm1792a driver, due to bug in kernel pcm179x: missing .cache_type in regmap_config
    [jedac5_bcm.c, jedac5_codec.c]
2026-01-21 Change 'compatible' driver name from ti to jve
2026-01-22 further change name of compatible driver to jve1792a
2026-01-22 fix use of 'of_node_put', fix 'i2c_codec_node'
    [jedac5_bcm.c]
2026-01-22 fix .name=null when setting node ptr
    [jedac5_bcm.c]
2026-01-26 Fix old leftover in codec
    [jedac_codec.c]
2026-01-26 Cleanup pcm1792 driver and dts reference
2026-01-26 Update bcm: try to avoid crash
    [jedac_bcm.c]
2026-01-26 fix 'compatible' names in .c and .dts
    [jedac_bcm.c]
2026-01-26 fix jedac_bcm register message
    [jedac_bcm.c]
2026-01-27 handle i2c bus errs in codec
2026-01-29 Add DAPM power management to take device out of standby mode'
2026-01-30 Fix register init of pcm1792 dacs
    [jedac_bcm.c]
2026-01-30 Fix register init of pcm1792 dacs - debug
    [jedac_bcm.c]
2026-01-30 Added 'regcache_cache_only', and debug prints
2026-02-05 small fixes in bcm, set 'uisync' gpio
    [jedac_bcm.c]
2026-02-05 fix regmap allocation during probe
    [jedac_bcm.c]
2026-02-06 Fix power-on event
2026-02-06 Fix gpio pulldown, reduce test logging
    [jedac_bcm.c]
2026-02-06 Update dts form campatibility with more RPi models, make uisync pin a parameter, provide a systemd 'jedac.service'
    [config.txt]
2026-02-06 Codec guard actual i2c write for samplerate
2026-02-07 cleanup Makefile, initialize devicedriver md
2026-02-07 Move files from jedac_soc_modules one level up
    [config.txt]
2026-02-07 Updated README, describing the Pi device device driver
2026-02-07 Update pi driver README
2026-02-09 Extend README on dlna player and the device driver
2026-03-01 RPi driver: do not take input sel on power-up
2026-03-13 Remove 'defaults' from regmap, to avoid bad view on content
    [dacxo_bcm.c, dacxo_codec.c]
2026-03-14 Fix 'ui_sync' updates when RPi player present
    [dac.yaml]

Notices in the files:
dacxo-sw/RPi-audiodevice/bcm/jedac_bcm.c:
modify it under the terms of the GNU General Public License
